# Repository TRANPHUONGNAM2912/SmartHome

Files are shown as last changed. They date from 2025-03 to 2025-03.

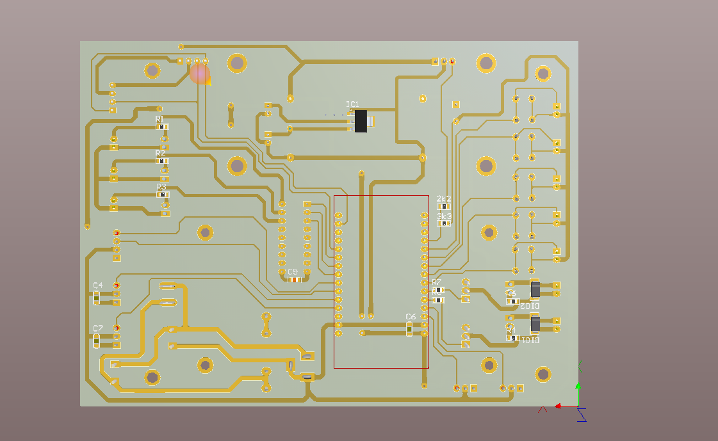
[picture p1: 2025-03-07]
Altium/SmartHome_DRW/Screenshot 2023-12-03 203835.png

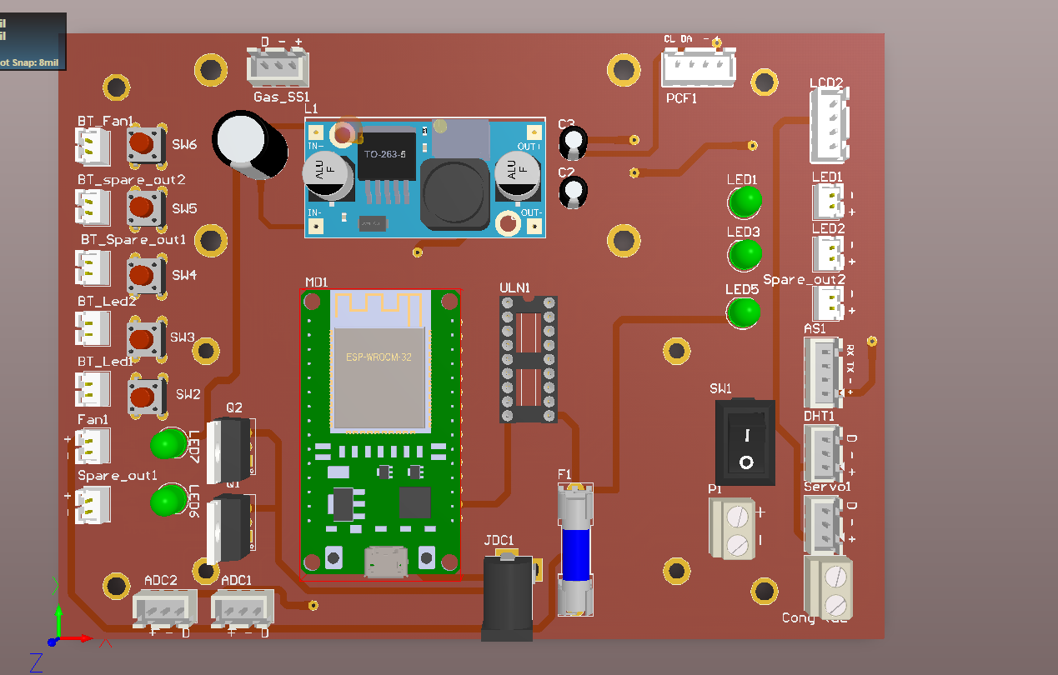
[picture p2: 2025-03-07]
Altium/SmartHome_DRW/2.png

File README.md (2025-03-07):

# Xây dựng mô hình nhà thông minh kết hợp xử lý ảnh
# Nội dung  
- Xây dựng mạch nguyên lý và mạch in trên phần mềm Altium  
- Mở cửa bằng mật khẩu số, vân tay hoặc nhận diện khuôn mặt  
- Servo mô phỏng cơ chế khóa điện tử tự động đóng mở theo xác thực  
- Nguồn dự phòng đảm bảo hệ thống vẫn hoạt động khi mất điện  
- Theo dõi nhiệt độ và độ ẩm tại phòng ngủ, phòng khách qua ứng dụng Blynk  
- Cảnh báo khí gas với hệ thống phát hiện nồng độ khí nguy hiểm  
- Xử lý sự cố tự động: Kích hoạt còi báo động và quạt hút khi phát hiện rò rỉ khí gas  
- Điều khiển thiết bị từ xa  
- Bật/tắt đèn thông qua ứng dụng điện thoại  
- Hẹn giờ tự động cho điều hòa và quạt  
- Giao diện điều khiển trực quan trên nền tảng Blynk  
# Phần mềm 
- Altium 21  
- Arduino IDE 2xx  
# Kết quả
Tham khảo video: https://www.youtube.com/watch?v=v8sgfzrXqkE&t=1s

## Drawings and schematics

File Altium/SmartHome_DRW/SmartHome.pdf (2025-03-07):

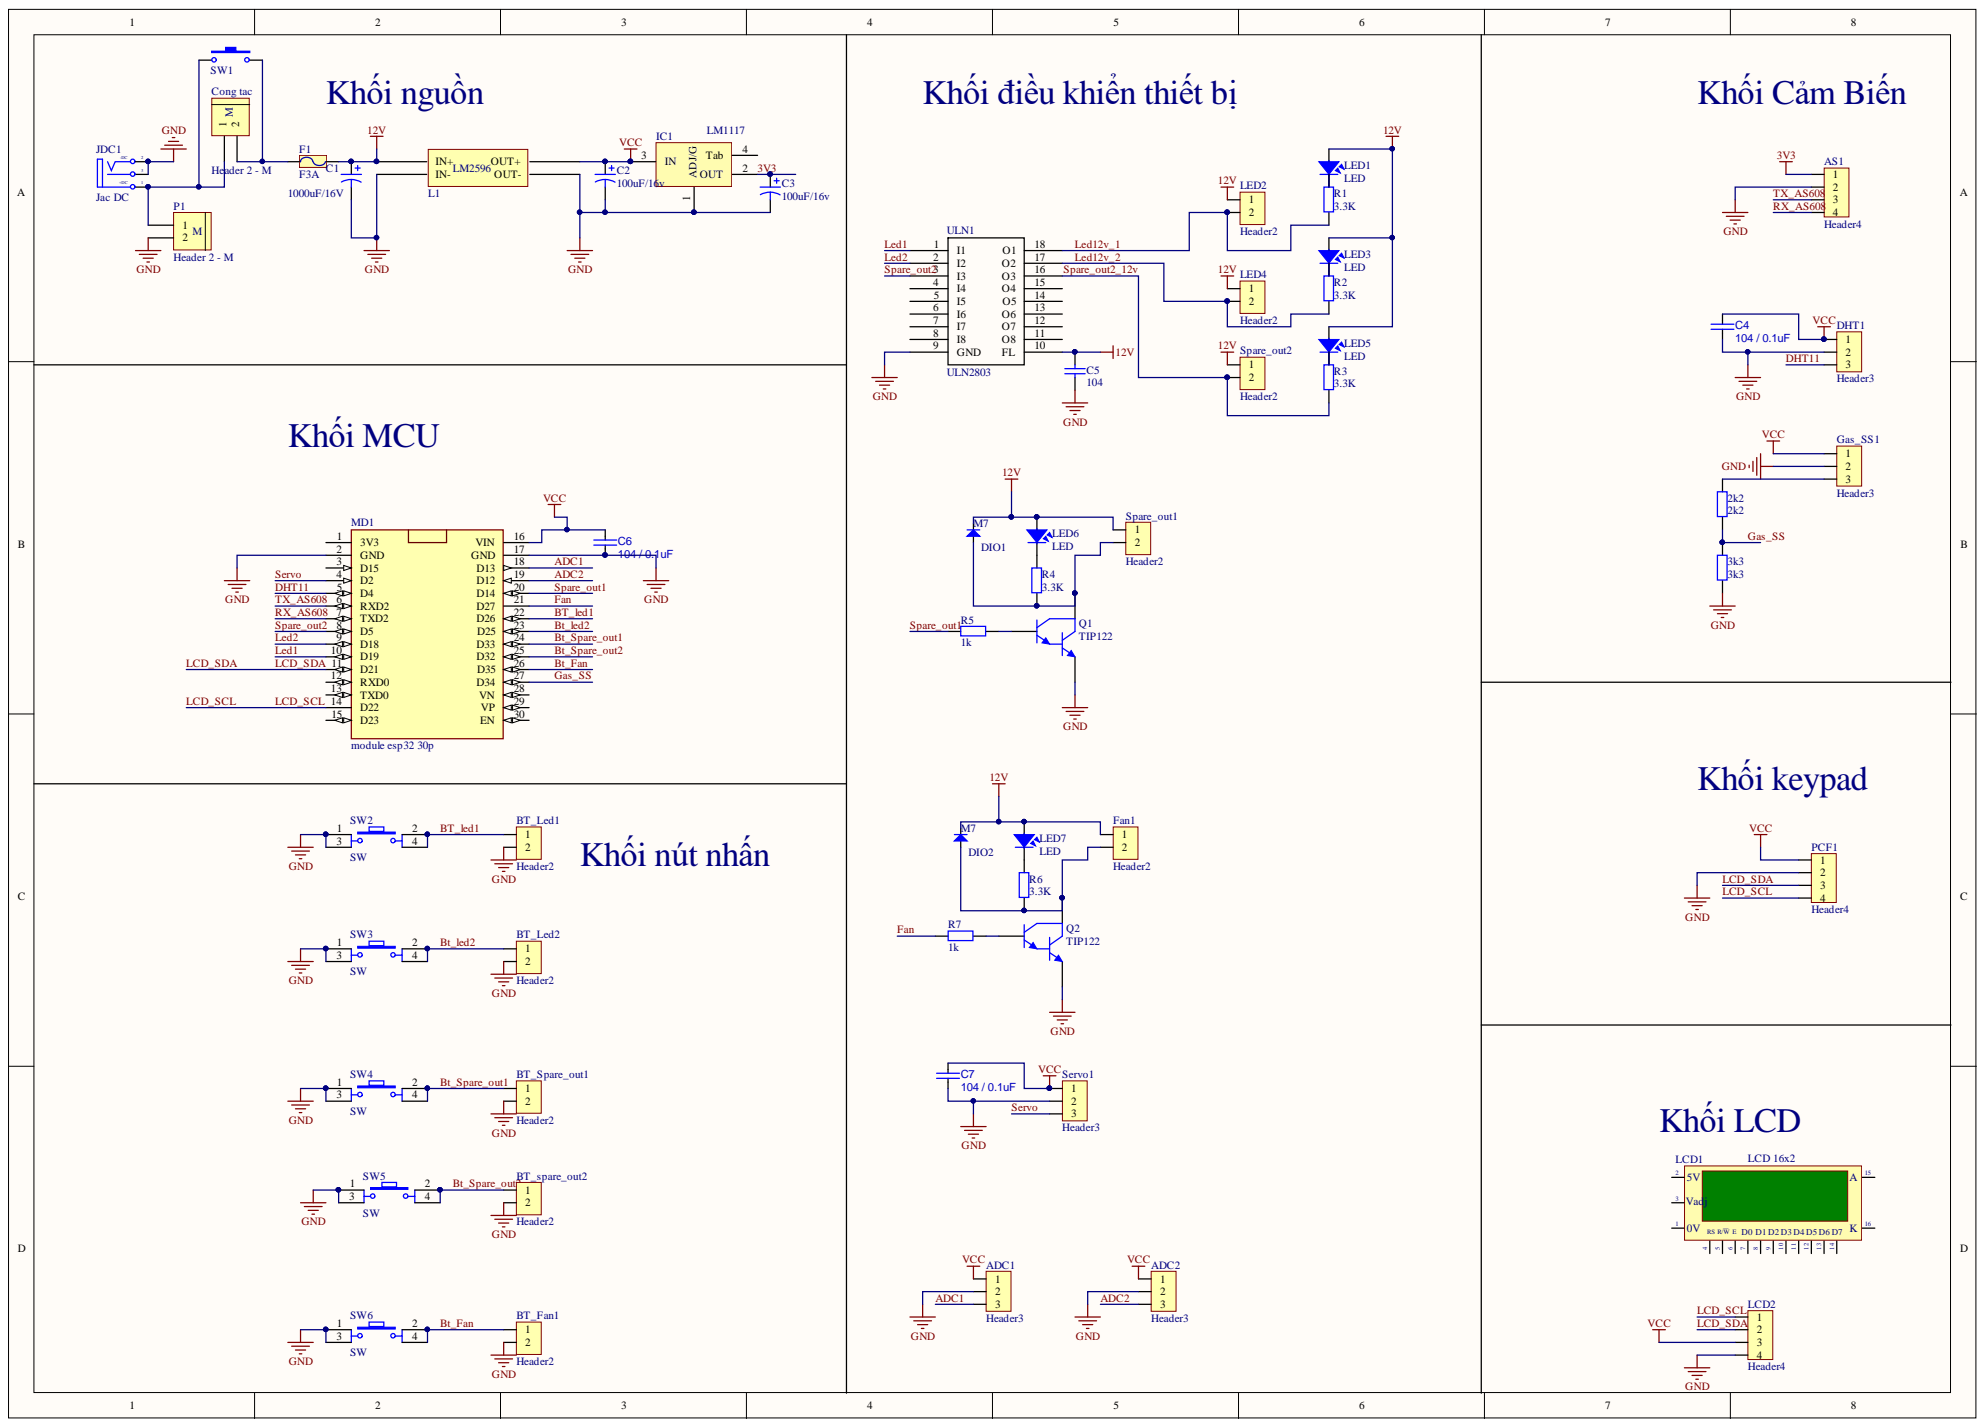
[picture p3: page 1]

Khối điều khiển thiết bị

ADJ/G 1 OUT 2 IN 3 Tab 4

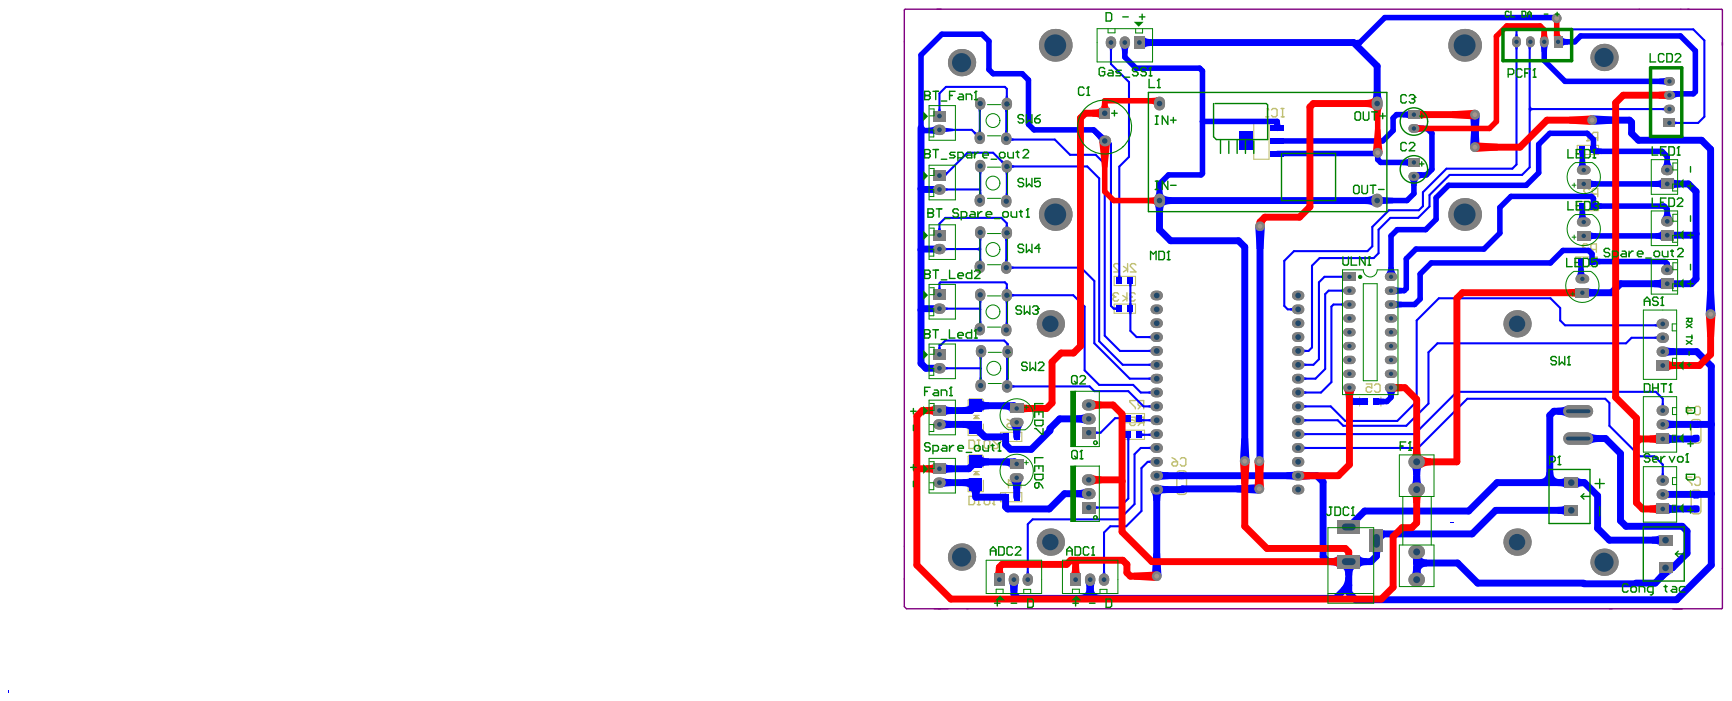
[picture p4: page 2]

Comment | Description | Designator | Footprint | LibRef | Quantity
2k2 | Resistor SMD 0805 | 2k2 | DIEN TRO 0805 | R0805 | 1
3k3 | Resistor SMD 0805 | 3k3 | DIEN TRO 0805 | R0805 | 1
Header3 | Header IDC, 3 x 1 Pin Vertical 2.54mm Pitch (Non-Boxed, Male) | ADC1, ADC2, DHT1, Gas_SS1, Servo1 | Header3 | Header3 | 5
Header4 | Header IDC, 4 x 1 Pin Vertical 2.54mm Pitch (Non-Boxed, Male) | AS1 | Header4 | Header4 | 1
Header2 | Header IDC, 2 x 1 Pin Vertical 2.54mm Pitch (Non-Boxed, Male) | BT_Fan1, BT_Led1, BT_Led2, BT_Spare_out1, BT_spare_out2, Fan1, LED2, LED4, Spare_out1, Spare_out2 | Header2 | Header2 | 10
1000uF/16V | Polarized Capacitor (Axial) | C1 | C10mm | Cap Pol 12mm | 1
100uF/16v | Polarized Capacitor (Axial) | C2, C3 | C5mm | Cap Pol 5mm | 2
approved sub OK | Capacitor SMD Cer 1.8nF 10% 50V X7R 0805 | C4, C6, C7 | CAP_0805 | CAP C_0805 | 3
104 | Capacitor | C5 | C0805 | CapSMD | 1
Header 2 - M | Header, 2-Pin, Medium | Cong tac, P1 | Medium - Header 2 | Header 2 - M | 2
M7 | Default Diode | DIO1, DIO2 | DIO-SMD-106 | Diode SMD | 2
F3A | Fuse | F1 | Fuse | Fuse | 1
LM1117 | 3v3 | IC1 | SOT223-4N | LM1117 | 1
Jac DC | Jac DC input | JDC1 | DC-IN | DCIN | 1
BUCK_LM2596 | | L1 | BUCK_LM2596 | BUCK_LM2596 | 1
LCD 16x2 | | LCD1 | LCD16X2N | LCD | 1
Header4 | Header IDC, 4 x 1 Pin Vertical 2.54mm Pitch (Non-Boxed, Male) | LCD2, PCF1 | XH2.54M-4 | Header4 | 2
LED | LED Single colour Green and Red | LED1, LED3, LED5, LED6, LED7 | LED-5 GRe | LED | 5
module esp32 30p | | MD1 | module esp32 30 pin | module esp32 30p | 1
TIP122 | Darlington Silicon Power NPN Transistor, 8 Amp, 100 Volts and 65 Watts | Q1, Q2 | QTO-220 | TIP122 | 2
3.3K | Resistor SMD 0805 | R1, R2, R3, R4, R6 | DIEN TRO 0805 | R0805 | 5
1k | Resistor SMD 0805 | R5, R7 | DIEN TRO 0805 | R0805 | 2
KCD01-11_SWITCH | Nut Nhan 2 Chan SMD 3x6x2.5 | SW1 | KCD01-11 | KCD01-11_SWITCH | 1
SW | Switch button 4 pin | SW2, SW3, SW4, SW5, SW6 | SW4 | SW4 | 5
ULN2803 | OCTAL HIGH CURRENT DULN1 | | DIP18/W0.3 | ULN2803 | 1

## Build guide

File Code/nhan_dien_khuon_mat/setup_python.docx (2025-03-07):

video hưỡng dẫn cài và thêm thư viện: https://www.youtube.com/watch?v=ERaBVJE9sHM

Cài đặt python theo file đã có trong folder, phải tich vào cái Add python to PATH như ảnh

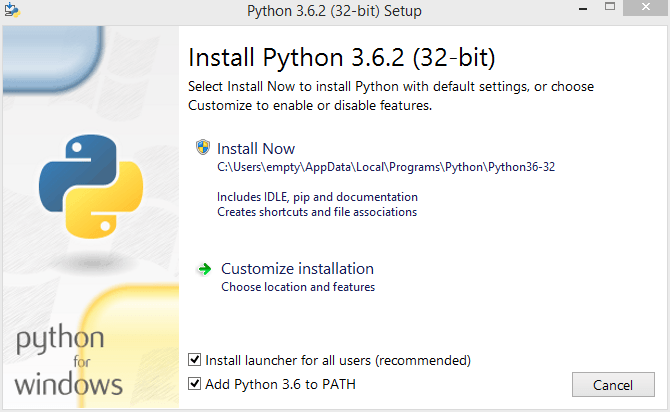
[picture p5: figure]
Python Cơ Bản] Phần 2: Cách cài đặt Python trên Windows, macOS, Linux

Cài python xong thì vào Command prompt gõ lần lượt lệnh sau để cài thư viện, sau khi gõ mỗi lệnh thì nhấn enter để nó tự cài, trường hợp lỗi

pip install opencv-python

pip install opencv-contrib-python

pip install numpy

pip install pillow

pip install pyserial

Chạy code

Khi chưa kết nối với esp32 thì chạy file test1.py

Khi đã kết nối esp32 thì chạy file test 2.py, trước khi chạy thì sửa cổng COM trong code sao cho đúng với thực tế:

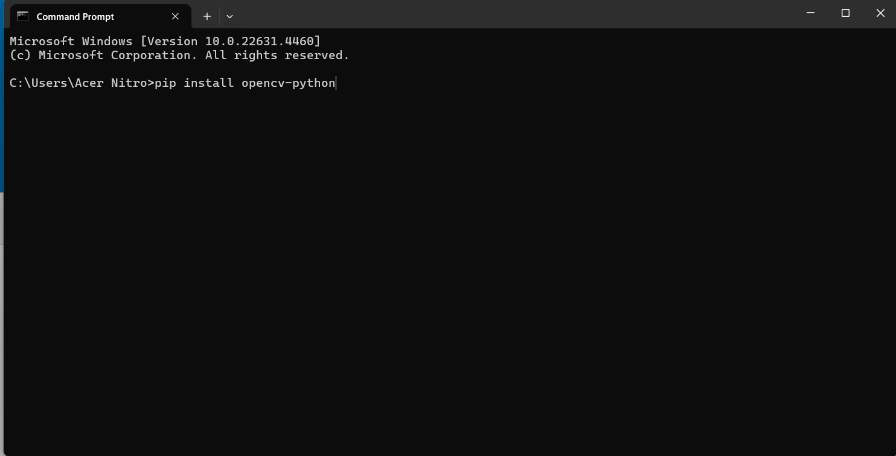
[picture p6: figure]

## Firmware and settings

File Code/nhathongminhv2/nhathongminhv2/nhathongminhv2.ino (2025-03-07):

//tài khoản blynk
// tk: 
// mk: 
#define BLYNK_TEMPLATE_ID "TMPL6scNnTrzH"
#define BLYNK_TEMPLATE_NAME "NHA THONG MINH IOT"
#include <Adafruit_Fingerprint.h>
#include <Key.h>
#include <Keypad.h>
#include <Keypad_I2C.h>
#include <Wire.h>
#include <LiquidCrystal_I2C.h>
#include <WiFi.h>
#include <BlynkSimpleEsp32.h>
#include "DHT.h"
#include <ESP32Servo.h>
#include <EEPROM.h> 
#define I2CADDR 0x20
#define PIN_SG90 2 
#define DHTTYPE DHT11
#define MODEM_RX 16
#define MODEM_TX 17
#define mySerial Serial2 
#define EEPROM_SIZE 1
Adafruit_Fingerprint finger = Adafruit_Fingerprint(&mySerial);
Servo sg90;
LiquidCrystal_I2C lcd(0x27, 16, 2);  
const int dht1Pin = 4;
const int dht2Pin = 13;
DHT dht1(dht1Pin, DHTTYPE);
DHT dht2(dht2Pin, DHTTYPE);
char auth[] = "df3Oy9bbjrwuDM2YH0uypox3G4zJLrCs"; 
char ssid[] = "tp-link"; 
char pass[] = "anhvu6868"; 
unsigned long lastTime = 0;
const int gasPin = 34; 
const int pir = 12; 
unsigned long startTime;
const unsigned long timeoutDuration = 5000;
int thresholdValue = 500; 
int gasValue = 0;
int alertState = 0; 
const int ledPin1 = 19;  // Chân điều khiển đèn 1
const int ledPin2 = 18;  // Chân điều khiển đèn 2
int fanpin = 27;
const int sw2 = 26;
const int sw3 = 25;
const int sw4 = 33;
const int sw5 = 32;
const int sw6 = 35;
bool prevSw2State = HIGH;
bool prevSw3State = HIGH;
bool prevSw4State = HIGH;
bool prevSw5State = HIGH;
bool prevSw6State = HIGH;
const byte ROWS = 4;
const byte COLS = 4;
char keys[ROWS][COLS] = {
  {'1', '2', '3', 'A'},
  {'4', '5', '6', 'B'},
  {'7', '8', '9', 'C'},
  {'*', '0', '#', 'D'}
};

byte rowPins[ROWS] = {0, 1, 2, 3};
byte colPins[COLS] = {4, 5, 6, 7};

Keypad_I2C keypad(makeKeymap(keys), rowPins, colPins, ROWS, COLS, I2CADDR);

char password[5] = "1234";
int a=0;
int check=0;
String inputString = "";
bool stringComplete = false;  
uint8_t id;
uint8_t checkTask = 0; 
int relay = 15;
unsigned long time1 = 0;
int valuepir=0;
boolean check1 = false;
int flag=0,flag1=0,flag3=0,flag2=0,flag4=0;
int count=0;
unsigned long previousMillis = 0;
const long interval = 5000; // Thời gian đèn sáng (5 giây)
bool pirState = false;
unsigned long previousGasMillis = 0;
const long gasInterval = 5000; // Thời gian chân 14 giữ mức HIGH (5 giây)
bool gasState = false;  // Trạng thái của giá trị gas

BlynkTimer timer;
unsigned long previousMillis1 = 0;  // Biến lưu thời điểm LED được bật
const long interval1 = 5000;        // Khoảng thời gian LED sáng (3 giây)
bool ledState1 = LOW;               // Trạng thái của LED

void setup() {
  Serial.begin(115200);
  Wire.begin();
  keypad.begin();
  sg90.setPeriodHertz(50); 
  sg90.attach(PIN_SG90, 500, 2400);
  dht1.begin();
  dht2.begin();
  lcd.init(); 
  lcd.backlight(); 
  sg90.write(180);
  pinMode(pir, INPUT);
  pinMode(14, OUTPUT);
  pinMode(sw2, OUTPUT);
  pinMode(sw3, OUTPUT);
  pinMode(sw4, OUTPUT);
  pinMode(sw5, OUTPUT);
  pinMode(sw6, INPUT);
  pinMode(ledPin1, OUTPUT);
  pinMode(ledPin2, OUTPUT);
  pinMode(fanpin, OUTPUT);
  pinMode(gasPin, INPUT);
  startTime = millis();
  WiFi.begin(ssid, pass);
  
  while (WiFi.status() != WL_CONNECTED && (millis() - startTime) < timeoutDuration) {
    lcd.setCursor(2,0); 
    lcd.print("DANG KET NOI"); 
    lcd.setCursor(8,1); 
    lcd.print("WIFI");
    Serial.println("Connecting to WiFi...");
    delay(250);
  }
  // Serial.println("Connected to WiFi");
  if (WiFi.status() == WL_CONNECTED) {
    Blynk.begin(auth, ssid, pass);
  }
  if (WiFi.status() != WL_CONNECTED) {
     Serial.println("Failed to connect to WiFi");
    lcd.clear();
    lcd.setCursor(1, 0); 
    lcd.print("KHONG KET NOI");
    lcd.setCursor(3, 1); 
    lcd.print("DUOC WIFI");
    delay(2000);
  }
  Serial.println("Connected to WiFi");

  // Blynk.begin(auth, ssid, pass);
  while (!Serial);  // For Yun/Leo/Micro/Zero/...
  delay(100);
  Serial.println("\n\nAdafruit Fingerprint sensor enrollment");
  // set the data rate for the sensor serial port
  finger.begin(57600);
  if (finger.verifyPassword()) {
    Serial.println("Found fingerprint sensor!");
  } else {
    Serial.println("Did not find fingerprint sensor :(");
    while (1) { delay(1); }
  }
 
  Serial.println(F("Reading sensor parameters"));
  finger.getParameters();
  Serial.print(F("Status: 0x")); Serial.println(finger.status_reg, HEX);
  Serial.print(F("Sys ID: 0x")); Serial.println(finger.system_id, HEX);
  Serial.print(F("Capacity: ")); Serial.println(finger.capacity);
  Serial.print(F("Security level: ")); Serial.println(finger.security_level);
  Serial.print(F("Device address: ")); Serial.println(finger.device_addr, HEX);
  Serial.print(F("Packet len: ")); Serial.println(finger.packet_len);
  Serial.print(F("Baud rate: ")); Serial.println(finger.baud_rate);
  finger.getTemplateCount();
  Serial.print(F("Sensor contains: ")); Serial.print(finger.templateCount); Serial.println(" templates");
  digitalWrite(sw2, HIGH);
  digitalWrite(sw3, HIGH);
  digitalWrite(sw4, HIGH);
  digitalWrite(sw5, HIGH);
  EEPROM.begin(32);
  for (int i = 0; i < 4; i++) {
    password[i] = EEPROM.read(i);
  }
  lcd.setCursor(2,0); 
  lcd.print("NHAP PASS SO"); 
  lcd.setCursor(2,1); 
  lcd.print("HOAC VAN TAY");
  timer.setInterval(1000, sensor);
}
void Seriall() {
    if (Serial.available() > 0) {  // Kiểm tra nếu có dữ liệu Serial
    sg90.write(0);
        // digitalWrite(19, HIGH);    // Bật LED
        previousMillis1 = millis(); // Ghi lại thời điểm hiện tại
        ledState1 = HIGH;          // Cập nhật trạng thái LED
        // Đọc dữ liệu từ Serial để xóa bộ đệm (optional)
        Serial.read();
    }
}
void loop() {
    Blynk.run();
  timer.run();
  unsigned long currentMillis = millis();  // Lấy thời gian hiện tại

    // Kiểm tra nếu LED đang bật và đã qua 3 giây
    if (ledState1 == HIGH && currentMillis - previousMillis1 >= interval1) {
        // digitalWrite(19, LOW);  // Tắt LED
        ledState1 = LOW;        // Cập nhật trạng thái LED
        sg90.write(135);
    }

    Seriall();  // Gọi hàm kiểm tra dữ liệu Serial
 Serial.println(digitalRead(pir));
if(digitalRead(pir) == 1 && pirState == false) {
    digitalWrite(ledPin2, HIGH); // Bật đèn
    previousMillis = millis(); // Ghi lại thời gian hiện tại
    pirState = true; // Đánh dấu đã phát hiện chuyển động
  }

  // Kiểm tra nếu đã hết 5 giây từ lần cuối cảm biến phát hiện chuyển động
  if(pirState == true && millis() - previousMillis >= interval) { 
    digitalWrite(ledPin2, LOW); // Tắt đèn sau 5 giây
    pirState = false; // Đặt lại trạng thái để sẵn sàng phát hiện chuyển động tiếp theo
  }

  phimso();
  vantay();
  led();
  if(flag>3){
    Blynk.virtualWrite(V9, 1);
    delay(100);
    flag=0;
  }
  if(flag<=3){
    Blynk.virtualWrite(V9, 0);
  }
    if(flag4>3){
    Blynk.virtualWrite(V9, 1);
    delay(100);
    flag4=0;
  }
  if(flag4<=3){
    Blynk.virtualWrite(V9, 0);
  }
  
  bool currentSw2State = digitalRead(sw2);
  if (currentSw2State == LOW && prevSw2State == HIGH) {
    if (digitalRead(ledPin1) == HIGH) {
      digitalWrite(ledPin1, LOW);
      delay(100);
      Blynk.virtualWrite(V6, LOW);
    } else {
      digitalWrite(ledPin1, HIGH);
      delay(100);
      Blynk.virtualWrite(V6, HIGH);
    }
  }
  prevSw2State = currentSw2State; 
 
  // bool currentSw3State = digitalRead(sw3);
  // if (currentSw3State == LOW && prevSw3State == HIGH) {
  //   if (digitalRead(ledPin2) == HIGH) {
  //     digitalWrite(ledPin2, LOW);
  //     delay(100);
  //     Blynk.virtualWrite(V7, LOW);
  //   } else {
  //     digitalWrite(ledPin2, HIGH);
  //     delay(100);
  //     Blynk.virtualWrite(V7, HIGH);
  //   }
  // }
  // prevSw3State = currentSw3State; 
  // Serial.println(digitalRead(sw6));
  bool currentSw6State = digitalRead(sw6);
  if (currentSw6State == LOW && prevSw6State == HIGH) {
    if (digitalRead(fanpin) == HIGH) {
      digitalWrite(fanpin, LOW);
      delay(100);
      Blynk.virtualWrite(V8, LOW);
    } else {
      digitalWrite(fanpin, HIGH);
      delay(100);
      Blynk.virtualWrite(V8, HIGH);
    }
  }
  prevSw6State = currentSw6State; 
}
void sensor(){

  gasValue = analogRead(gasPin);
  Blynk.virtualWrite(V4, gasValue); 
  if(gasValue >= thresholdValue && gasState == false) {
    digitalWrite(14, HIGH); // Đặt chân 14 ở mức HIGH
    previousGasMillis = millis(); // Ghi lại thời gian hiện tại
    gasState = true; // Đánh dấu đã đạt ngưỡng gas
  }

  // Kiểm tra nếu đã hết 5 giây từ lúc giá trị gas đạt ngưỡng
  if(gasState == true && millis() - previousGasMillis >= gasInterval) {
    digitalWrite(14, LOW); // Đặt chân 14 ở mức LOW sau 5 giây
    gasState = false; // Đặt lại trạng thái để sẵn sàng cho lần đo tiếp theo
  }

  float humidity1 = dht1.readHumidity();
  float temperature1 = dht1.readTemperature();
  float humidity2 = dht2.readHumidity();
  float temperature2 = dht2.readTemperature();
  Blynk.virtualWrite(V0, temperature1);
  Blynk.virtualWrite(V1, humidity1);
  Blynk.virtualWrite(V2, temperature2);
  Blynk.virtualWrite(V3, humidity2);
}


BLYNK_WRITE(V5) {
  thresholdValue = param.asInt(); 
}
BLYNK_WRITE(V6) {
  int led1state = param.asInt(); 
  digitalWrite(ledPin1, led1state);
}
BLYNK_WRITE(V7) {
  int led2state = param.asInt(); 
  digitalWrite(ledPin2, led2state);
}
BLYNK_WRITE(V8) {
  int fanstate = param.asInt(); 
  digitalWrite(fanpin, fanstate);
}

void phimso(){
  char key = keypad.getKey();
  
  if (key) {
      
    a++;
    Serial.println(key);
    if(a==1){
      lcd.clear();
    }  
    lcd.setCursor(a+4,0);
    lcd.print("*"); 
    if(a==4){
      lcd.clear();
      lcd.setCursor(2,0); 
      lcd.print("MAT KHAU SAI"); 
      lcd.setCursor(2,1); 
      lcd.print("HAY NHAP LAI");
      a=0;
    }
    if (key == 'C') {
      checkpass();
      changePassword();
    } 
    if (key == 'A') {
    checkpass();
    // Kiểm tra vân tay mới có khớp với vân tay trong cơ sở dữ liệu không
    Serial.println("Checking fingerprint...");
    
      // Nếu vân tay mới khớp, bắt đầu quá trình thêm vân tay mới
      Serial.println("Fingerprint matched. Adding new fingerprint...");
      checkTask = 1;
     
    } else if (key == 'D') {
      checkpass();
      // Xoá tất cả dấu vân tay
      Serial.println("Deleting all fingerprints...");
      lcd.clear();
      lcd.setCursor(2,0); 
      lcd.print("DELETE ALL"); 
      lcd.setCursor(2,1); 
      lcd.print("FINGERPRINTS");
      delay(1000);
      finger.emptyDatabase();
      Serial.println("Now database is empty");
    }
    else if (checkPassword(key)==true) {
      lcd.clear();
      lcd.setCursor(3,0);
      lcd.print("OPEN DOOR");
      Blynk.virtualWrite(V0, 1);
      delay(1000);
      
      a=0;
      lcd.setCursor(2,0); 
      lcd.print("NHAP PASS SO"); 
      lcd.setCursor(2,1); 
      lcd.print("HOAC VAN TAY"); 
      sg90.write(0);
      
      Serial.println("a");
      check=1;
      lastTime = millis();
    }
  }
  // Serial.println(millis()-lastTime);
  if (check==1 && millis() - lastTime >= 3000) {
      sg90.write(135);
      Blynk.virtualWrite(V0, 0);
      check =0;
      Serial.println("tatled");
    }
}
bool checkPassword(char key) {
  static int index = 0;
  if (key == password[index]) {
    index++;
    if (index == 4) {
      index = 0; 
      return true; 
      flag=0;
    }
  } else {
    index = 0; 
    count++;
    if(count==4){
      flag++;
      count=0;
    }
    if(flag>4){
      flag=1;
    }
  }
  return false;
}
void checkpass(){
    bool passwordAccepted = false;
  while (!passwordAccepted) {
    Serial.println("Enter current password:");
    lcd.clear();
    lcd.setCursor(0,0);
    lcd.print("CURRENT PASSWORD:"); 
   
    char entered_password[5] = {'\0', '\0', '\0', '\0', '\0'};

    // Nhập mật khẩu cũ
    for (int i = 0; i < 4; i++) {
      char key = keypad.getKey();
      while (key == NO_KEY) {
        key = keypad.getKey();
      }
      entered_password[i] = key;
      Serial.print('*');
      lcd.setCursor(i+5,1);
      lcd.print("*"); 
    }

    // Kiểm tra mật khẩu cũ
    if (checkEnteredPassword(entered_password)) {
      passwordAccepted = true;
    } else {
      Serial.println("\nIncorrect password. Please try again.");
    }
  }
}
void changePassword() {

  lcd.clear();
  lcd.setCursor(2,0);
  lcd.print("NEW PASSWORD:"); 
  Serial.println("Enter new password:");
  char new_password[5] = {'\0', '\0', '\0', '\0', '\0'};
  for (int i = 0; i < 4; i++) {
    char key = keypad.getKey();
    while (key == NO_KEY) {
      key = keypad.getKey();
      // Serial.println(i);
      if(i>0){
      lcd.setCursor(i+5,1);
      lcd.print("*"); 
      }
    }
    new_password[i] = key;
    Serial.print('*'); 

  }
  if (new_password[0] != '\0') {
    for (int i = 0; i < 4; i++) {
      password[i] = new_password[i];
      EEPROM.write(i, password[i]);
      EEPROM.commit();
    }
    lcd.clear();
    lcd.setCursor(3,0);
    lcd.print("DA THAY DOI"); 
    lcd.setCursor(4,1);
    lcd.print("MAT KHAU"); 
    Blynk.virtualWrite(V1, 0);
    delay(1000);
    a=0;
    lcd.setCursor(2,0); 
    lcd.print("NHAP PASS SO"); 
    lcd.setCursor(2,1); 
    lcd.print("HOAC VAN TAY");
    Serial.println("\nPassword changed successfully!");
    flag2=0;
  } else {
    lcd.clear();
    lcd.setCursor(6,0);
    lcd.print("LOI");
    delay(1000);
    Serial.println("\nPassword change canceled.");
  }
}
bool checkEnteredPassword(char* entered_password) {
  for (int i = 0; i < 4; i++) {
    if (entered_password[i] != password[i]) {
      flag++;
      return false;
    }
  }
  return true;
  flag=0;
}
void vantay(){
  getFingerprintID();
  delay(50);            //don't ned to run this at full speed.
  if(checkTask == 1) //Add template fingerprint
  {
    Serial.println("Ready to enroll a fingerprint!");
    Serial.println("Please type in the ID # (from 1 to 127) you want to save this finger as...");
    lcd.clear();
    lcd.setCursor(0,0); 
    lcd.print("NHAP ID VAN TAY"); 
    lcd.setCursor(6,1); 
    lcd.print("ID=");
    id = readnumber();
    lcd.setCursor(9,1); 
    lcd.print(id); 
    checkTask = 0;
    Blynk.virtualWrite(V2, 0);
    if (id == 0) {// ID #0 not allowed, try again!
       return;
    }
    Serial.print("Enrolling ID #");
    Serial.println(id);
    while (!  getFingerprintEnroll() )
    {
    }
    checkTask = 0;
  }
  else if(checkTask == 2) //check template
  {
    checkTask = 0;
    uint8_t p = finger.loadModel(id);
    if(p == FINGERPRINT_OK)
    {
      Serial.print("ID ");
      Serial.print(id);
      Serial.println(" is exist");
    }
    else
    {
      Serial.print("ID ");
      Serial.print(id);
      Serial.println(" is NO exist");
    }
  }
  else if(checkTask == 3) //delete template
  {
    checkTask = 0;
    if(id == 0) //delete all template
    {
      finger.emptyDatabase();
      Serial.println("Now database is empty");
    }
    else
      deleteFingerprint(id);
  }
}
void serialEvent() {
  while (Serial.available()) {
    // get the new byte:
    char inChar = (char)Serial.read();
    // add it to the inputString:
    inputString += inChar;
    // if the incoming character is a 'X', set a flag so the main loop can
    // do something about it:
    if (inChar == 'X') {
      if(inputString[0] == 'C' && inputString[4] == 'X') //to check ID
      {
        id = (inputString[1] - 48)*100 + (inputString[2] - 48)*10 + (inputString[3] - 48);
        checkTask = 2;
        Serial.print("Check ID...");
        Serial.println(id);
      }
      else if(inputString == "ADDX") //add new fingerprint
      {
        Serial.println("Add fingerprint...");
        checkTask = 1;
      }
      else if(inputString[0] == 'D' && inputString[4] == 'X') //delete fingerprint in memmory
      {
        id = (inputString[1] - 48)*100 + (inputString[2] - 48)*10 + (inputString[3] - 48);
        Serial.print("Delete template ID...");
        Serial.println(id);
        checkTask = 3;
      }
    }
  }
  inputString = "";
}
 
uint8_t readnumber(void) {
  char key;
  uint8_t num = 0;

  while (num == 0) {
    key = keypad.getKey();

    // Nếu key là một số từ '1' đến '9', chuyển đổi thành số nguyên và gán cho biến num
    if (key >= '1' && key <= '9') {
      num = key - '0';  // Chuyển đổi ký tự sang số nguyên
    }
  }

  return num;
}
 
uint8_t getFingerprintID() {
  uint8_t p = finger.getImage();
  switch (p) {
    case FINGERPRINT_OK:
      Serial.println("Image taken");
      break;
    case FINGERPRINT_NOFINGER:
      // Serial.println("No finger detected");
      return p;
    case FINGERPRINT_PACKETRECIEVEERR:
      Serial.println("Communication error");
      return p;
    case FINGERPRINT_IMAGEFAIL:
      Serial.println("Imaging error");
      return p;
    default:
      Serial.println("Unknown error");
      return p;
  }
  // OK success!
  p = finger.image2Tz();
  switch (p) {
    case FINGERPRINT_OK:
      Serial.println("Image converted");
      break;
    case FINGERPRINT_IMAGEMESS:
      Serial.println("Image too messy");
      return p;
    case FINGERPRINT_PACKETRECIEVEERR:
      Serial.println("Communication error");
      return p;
    case FINGERPRINT_FEATUREFAIL:
      Serial.println("Could not find fingerprint features");
      return p;
    case FINGERPRINT_INVALIDIMAGE:
      Serial.println("Could not find fingerprint features");
      return p;
    default:
      Serial.println("Unknown error");
      return p;
  }
  // OK converted!
  p = finger.fingerSearch();
  if (p == FINGERPRINT_OK) {
    Serial.println("Found a print match!");
    flag4=0;

  } else if (p == FINGERPRINT_PACKETRECIEVEERR) {
    Serial.println("Communication error");
    return p;
  } else if (p == FINGERPRINT_NOTFOUND) {
    Serial.println("Did not find a match");
    flag4++;
    
    return p;
  } else {
    Serial.println("Unknown error");
    return p;
  }
 
  // found a match!
  Serial.print("Found ID #"); Serial.print(finger.fingerID);
  Serial.print(" with confidence of "); Serial.println(finger.confidence);
  check1 = true;
  lcd.clear();
  lcd.setCursor(3,0);
  lcd.print("OPEN DOOR");
  
  sg90.write(0);
  // Serial.println(" Relay ON ");
  // delay(2000);
  // digitalWrite(relay, LOW); // Control relay
  // Serial.println(" Relay OFF ");
  return finger.fingerID;
}
void led(){
  unsigned long time2 = millis();
  // Serial.println(time2-time1);
  if(check1 == true){
    if(time2-time1>=3000){
      Blynk.virtualWrite(V0, 0);
      sg90.write(135);
      time1 = time2;
      check1 = false;
      lcd.clear();
      lcd.setCursor(2,0); 
      lcd.print("NHAP PASS SO"); 
      lcd.setCursor(2,1); 
      lcd.print("HOAC VAN TAY");

    }

  }
  else{
    time1=time2;
  }

}
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

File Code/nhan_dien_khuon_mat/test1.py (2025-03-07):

import cv2
import os
import numpy as np
from PIL import Image
import tkinter as tk
from tkinter import simpledialog, messagebox
from threading import Thread

# Biến toàn cục để quản lý luồng và dừng chương trình
running_thread = None
stop_event = False

def stop_program():
    global stop_event
    if running_thread and running_thread.is_alive():
        stop_event = True
        print("\n[INFO] Đang dừng chương trình...")
        running_thread.join()  # Đợi cho luồng kết thúc
        print("\n[INFO] Chương trình đã dừng.")
    else:
        print("\n[INFO] Không có chương trình nào đang chạy.")

def reset_stop_event():
    global stop_event
    stop_event = False

def run_function1(face_id):
    global stop_event
    reset_stop_event()

    cam = cv2.VideoCapture(0)
    cam.set(3, 640)
    cam.set(4, 480)

    face_detector = cv2.CascadeClassifier('haarcascade_frontalface_default.xml')
    print("\n [INFO] Khởi Tạo Camera ...")
    count = 0

    while not stop_event:
        ret, img = cam.read()
        img = cv2.flip(img, 1)
        gray = cv2.cvtColor(img, cv2.COLOR_BGR2GRAY)
        faces = face_detector.detectMultiScale(gray, 1.1, 5)

        # Hiển thị thông báo lên khung hình
        cv2.putText(img, "Dua khuon mat vao khung hinh", (10, 30), 
                    cv2.FONT_HERSHEY_SIMPLEX, 0.7, (0, 255, 0), 2, cv2.LINE_AA)
        cv2.putText(img, f"Anh da chup: {count}", (10, 60), 
                    cv2.FONT_HERSHEY_SIMPLEX, 0.7, (255, 255, 0), 2, cv2.LINE_AA)

        for (x, y, w, h) in faces:
            cv2.rectangle(img, (x, y), (x + w, y + h), (255, 0, 0), 2)
            count += 1
            cv2.imwrite("dataset/User." + str(face_id) + '.' + str(count) + ".jpg", gray[y:y + h, x:x + w])

        cv2.imshow('image', img)
        k = cv2.waitKey(100) & 0xff
        if k == 27 or count >= 100:
            break

    print("\n [INFO] Thoát")
    cam.release()
    cv2.destroyAllWindows()


def start_function1():
    face_id = simpledialog.askstring("Nhập ID", "Vui lòng nhập ID khuôn mặt:")
    if not face_id:
        print("\n[INFO] Không nhập ID, dừng chương trình.")
        return
    global running_thread
    running_thread = Thread(target=run_function1, args=(face_id,))
    running_thread.start()

def run_function2():
    path = 'dataset'
    recognizer = cv2.face.LBPHFaceRecognizer_create()
    detector = cv2.CascadeClassifier("haarcascade_frontalface_default.xml")

    def getImagesAndLabels(path):
        imagePaths = [os.path.join(path, f) for f in os.listdir(path)]
        faceSamples = []
        ids = []

        for imagePath in imagePaths:
            PIL_img = Image.open(imagePath).convert('L')
            img_numpy = np.array(PIL_img, 'uint8')
            id = int(os.path.split(imagePath)[-1].split(".")[1])
            faces = detector.detectMultiScale(img_numpy)

            for (x, y, w, h) in faces:
                faceSamples.append(img_numpy[y:y + h, x:x + w])
                ids.append(id)

        return faceSamples, ids

    print("\n [INFO] Đang training dữ liệu ...")
    faces, ids = getImagesAndLabels(path)
    recognizer.train(faces, np.array(ids))
    recognizer.write('trainer/trainer.yml')
    print("\n [INFO] {0} khuôn mặt được train. Thoát.".format(len(np.unique(ids))))

def run_function3():
    recognizer = cv2.face.LBPHFaceRecognizer_create()
    recognizer.read('trainer/trainer.yml')
    faceCascade = cv2.CascadeClassifier('haarcascade_frontalface_default.xml')

    font = cv2.FONT_HERSHEY_SIMPLEX
    names = ['0', 'Tran Phuong Nam', 'Phuoc', 'Dinh', '4', '5']

    cam = cv2.VideoCapture(0)
    cam.set(3, 640)
    cam.set(4, 480)
    minW = 0.1 * cam.get(3)
    minH = 0.1 * cam.get(4)

    while not stop_event:
        ret, img = cam.read()
        img = cv2.flip(img, 1)
        gray = cv2.cvtColor(img, cv2.COLOR_BGR2GRAY)

        faces = faceCascade.detectMultiScale(gray, scaleFactor=1.1, minNeighbors=5, minSize=(int(minW), int(minH)))

        for (x, y, w, h) in faces:
            cv2.rectangle(img, (x, y), (x + w, y + h), (0, 255, 0), 2)
            id, confidence = recognizer.predict(gray[y:y + h, x:x + w])

            if confidence < 100:
                id = names[id]
                confidence = "  {0}%".format(round(100 - confidence))
            else:
                id = "unknown"
                confidence = "  {0}%".format(round(100 - confidence))

            cv2.putText(img, str(id), (x + 5, y - 5), font, 1, (255, 255, 255), 2)
            cv2.putText(img, str(confidence), (x + 5, y + h - 5), font, 1, (255, 255, 255), 1)

        cv2.imshow('nhan dien khuon mat', img)
        k = cv2.waitKey(10) & 0xff
        if k == 27:
            break

    print("\n [INFO] Thoát")
    cam.release()
    cv2.destroyAllWindows()

def delete_face_data():
    face_id = simpledialog.askstring("Xóa dữ liệu", "Vui lòng nhập ID khuôn mặt để xóa:")
    if not face_id:
        print("\n[INFO] Không nhập ID, không thực hiện xóa.")
        return

    dataset_path = "dataset"
    files_deleted = 0

    if not os.path.exists(dataset_path):
        messagebox.showerror("Lỗi", "Thư mục dataset không tồn tại.")
        return

    for file in os.listdir(dataset_path):
        if file.startswith(f"User.{face_id}."):
            os.remove(os.path.join(dataset_path, file))
            files_deleted += 1

    if files_deleted > 0:
        messagebox.showinfo("Thành công", f"Đã xóa {files_deleted} tệp dữ liệu khuôn mặt với ID {face_id}.")
    else:
        messagebox.showinfo("Thông báo", f"Không tìm thấy dữ liệu khuôn mặt với ID {face_id}.")

def run_threaded_function(function):
    global running_thread
    running_thread = Thread(target=function)
    running_thread.start()

# Giao diện với tkinter
def create_interface():
    root = tk.Tk()
    root.title("Chương trình nhận diện khuôn mặt")
    root.geometry("300x300")

    btn1 = tk.Button(root, text="Chụp dữ liệu khuôn mặt", command=start_function1)
    btn1.pack(pady=10)

    btn2 = tk.Button(root, text="Train dữ liệu", command=lambda: run_threaded_function(run_function2))
    btn2.pack(pady=10)

    btn3 = tk.Button(root, text="Nhận diện khuôn mặt", command=lambda: run_threaded_function(run_function3))
    btn3.pack(pady=10)

    btn_delete = tk.Button(root, text="Xóa dữ liệu khuôn mặt", command=delete_face_data)
    btn_delete.pack(pady=10)

    btn_stop = tk.Button(root, text="Dừng chương trình", command=stop_program)
    btn_stop.pack(pady=10)

    root.mainloop()

if __name__ == "__main__":
    create_interface()
